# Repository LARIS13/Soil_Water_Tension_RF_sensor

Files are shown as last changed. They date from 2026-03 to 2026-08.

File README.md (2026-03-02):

# Soil_Water_Tension_RF_sensor
Implementation of Watermark sensor using arduino, attiny85 and RF modules including:

C++ code  
KiCad blueprints for PCB  
LaTeX document explaining theory, limitations and implementation of water measurement techniques.

# Dependencies:  
Manchester RF library: https://github.com/mchr3k/arduino-libs-manchester  
tinysnore is only used to sleep Attiny85 for more than the max Watchdog timer time, which is around 8 seconds: https://github.com/connornishijima/TinySnore

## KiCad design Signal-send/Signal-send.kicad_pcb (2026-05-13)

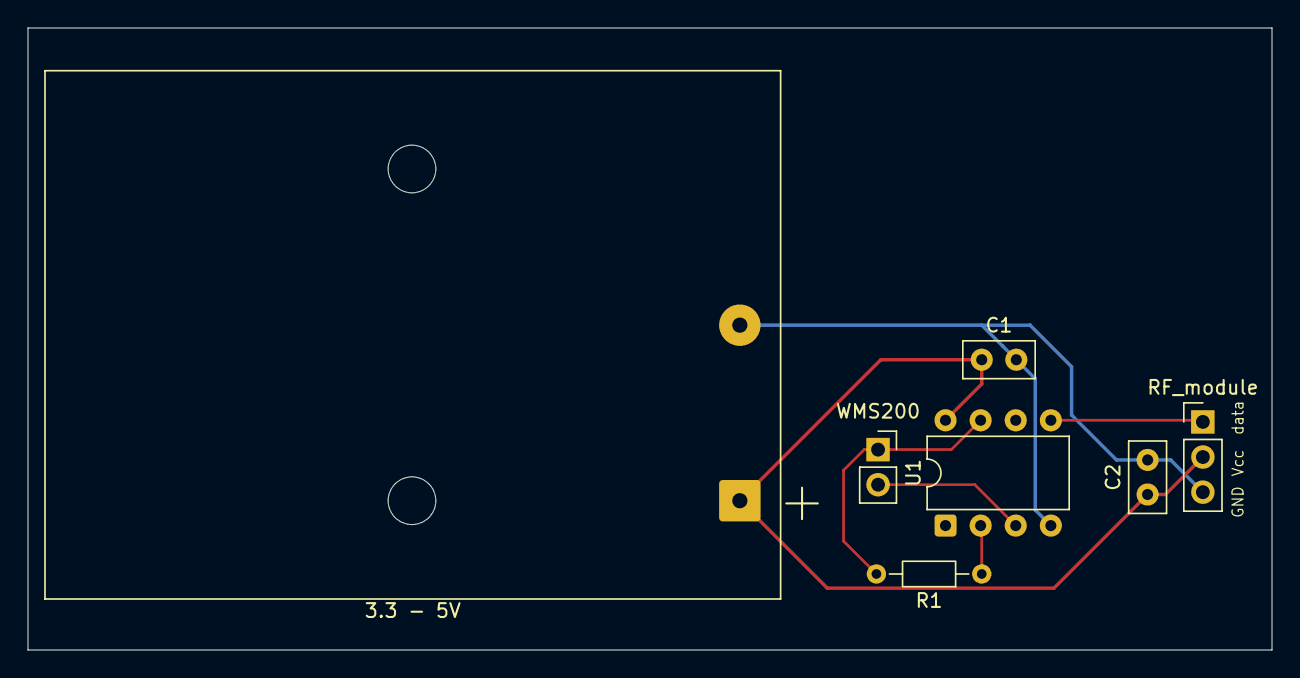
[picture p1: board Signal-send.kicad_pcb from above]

Board: 2 copper layers, 90.0 x 45.0 mm, 7 parts (0 on the bottom side), 5 nets.

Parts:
3.3 - 5V: BatteryHolder_Keystone_2479_3xAAA
C1: 0.1uF; C_Disc_D5.0mm_W2.5mm_P2.50mm
C2: 100uF; C_Disc_D5.0mm_W2.5mm_P2.50mm
R1: 10k; R_Axial_DIN0204_L3.6mm_D1.6mm_P7.62mm_Horizontal
RF_module: PinHeader_1x03_P2.54mm_Vertical
U1: ATtiny85V-10P; DIP-8_W7.62mm
WMS200: WMS200; PinSocket_1x02_P2.54mm_Vertical

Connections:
+5V: 3.3 - 5V.1, C1.1, C2.1, RF_module.2, U1.8 (VCC)
GNDREF: 3.3 - 5V.2, C1.2, C2.2, RF_module.3, U1.4 (GND)
unnamed: R1.2, U1.7 (PB2), WMS200.1
unnamed: R1.1, U1.2 (XTAL1/PB3)
unnamed: U1.3 (XTAL2/PB4), WMS200.2

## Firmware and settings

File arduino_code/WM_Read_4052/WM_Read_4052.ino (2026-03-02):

#include <math.h>

//************Documentation available at : www.irrometer.com/200ss.html ******************************************
// This program will read 3 Watermark(WM)Sensor(200-SS)and 1 Soil temperature sensor( 200TS) from Irrometer Co Inc.***
// Verson 1.0 updated 7/27/2023 by Jeremy Sullivan Irrometer Co Inc.**************************************************
//********************************************************************************************************************
// Watermark is a resistive sensor, so in order to check the accuracy of the resistive reading circuit a .....
// 10K resistor (1% precision) is used as a calibration reference only for prototype purposes.
// Code tested on Arduino Uno R3
// Purpose of this code is to demonstrate valid WM reading code, circuitry and excitation.
// This program uses a modified form of Dr. Shocks 1998 calibration equation
// Circuit will use a dual channel multiplexer to isolate sensors and will alternate polarity between the Sensor terminals for up to 4 resistive sensors( temperature/WM or calibration resistor)
// MUX control A and B to be controlled by PWM P4 & P3
// Sensor to be energized by PWM 5 or PWM 11, alternating between HIGH and LOW states
// MUX  enable/ disable PWM 6(LOW: Enable/High: Disable)
// Analog read channels to be used during MUX active : A1
// Channel 0 of MUX used for the temp sensor, channel 1 for Watermark 1, Channel 2 for Watermark 3 and and Channel 3 for Watermark 3
// In the absence of a Temp Sensor the program assigns 24 Degree C to temp for calibration of soil moisture tension

//NOTE: this code assumes a 10 bit ADC. Replace 1024 with 4096 if using a 12 bit ADC.
//NOTE: the 0.09 excitation time may not be sufficient depending on circuit design, cable lengths, voltage, etc. Increase if necessary to get accurate readings, do not exceed 0.2

//Truth table for MUX (B=PWM3 & A=PWM4)
//--B---A
//  0   0---- READ TEMPERATURE SENSOR
//  0   1---- READ WM1
//  1   0---- READ WM2
//  1   1---- READ WM3

// SET PWM5 or PWM11 HIGH/LOW ALTERNATELY TO EXCITE SENSOR

#define num_of_read 1 // number of iterations, each is actually two reads of the sensor (both directions)
const int Rx = 10000;  //fixed resistor attached in series to the sensor and ground...the same value repeated for all WM and Temp Sensor.
const long default_TempC = 24;
const long open_resistance = 35000; //check the open resistance value by replacing sensor with an open and replace the value here...this value might vary slightly with circuit components
const long short_resistance = 200; // similarly check short resistance by shorting the sensor terminals and replace the value here.
const long short_CB = 240, open_CB = 255 ;
const int SupplyV = 5; // Assuming 5V output for SupplyV, this can be measured and replaced with an exact value if required
const float cFactor = 1.1; //correction factor optional for adjusting curves. Traditionally IRROMETER devices used a different reading method, voltage divider circuits often require this adjustment to match exactly.
int i, j = 0, WM1_CB = 0, WM2_CB = 0, WM3_CB = 0;
float SenV10K = 0, SenVTempC = 0, SenVWM1 = 0, SenVWM2 = 0, ARead_A1 = 0, ARead_A2 = 0, WM3_Resistance = 0, WM2_Resistance = 0, WM1_Resistance = 0, TempC_Resistance = 0, TempC = 0;

void setup()
{
  // initialize serial communications at 9600 bps:
  Serial.begin(9600);

  // initialize the digital pins as outputs
  pinMode(3, OUTPUT);  //used for S0 control of the MUX 0-1
  pinMode(4, OUTPUT);  //used for S1 control of the MUX 0-1
  pinMode(5, OUTPUT);  //Sensor Vs or GND
  pinMode(6, OUTPUT);  //Enable disable MUX 0-1
  pinMode(11, OUTPUT);  //Sensor Vs or GND

  delay(100);   // time in milliseconds, wait 0.1 minute to make sure the OUTPUT is assigned
}

void loop()
{
  while (j == 0)
  {

    //enable the MUX
    digitalWrite(6, LOW);
    
    //Read the temp sensor
    delay(100); //0.1 second wait before moving to next channel or switching MUX
    //address the MUX (channel 1)
    
    digitalWrite(3, LOW);
    digitalWrite(4, LOW);

    delay(10); //wait for MUX
    
    TempC_Resistance = readWMsensor();

    //Read the first Watermark sensor
    delay(100); //0.1 second wait before moving to next channel or switching MUX
    //address the MUX
    digitalWrite(3, LOW);
    digitalWrite(4, HIGH);

    delay(10); //wait for the MUX

    WM1_Resistance = readWMsensor();

    //Read the second Watermark sensor
    delay(100); //0.1 second wait before moving to next channel or switching MUX
    //address the MUX 
    digitalWrite(3, HIGH);
    digitalWrite(4, LOW);

    delay(10); //wait for MUX

    WM2_Resistance = readWMsensor();

    //Read the third Watermark sensor
    delay(100); //0.1 second wait before moving to next channel or switching MUX
    //address the MUX
    digitalWrite(3, HIGH);
    digitalWrite(4, HIGH);

    delay(10); //wait for the MUX

    WM3_Resistance = readWMsensor();

    delay(100); //0.1 second wait before moving to next channel or switching MUX


    digitalWrite(6, HIGH);   //Disable MUX 0-1 pair
    delay(100); //0.1 second wait before moving to next channel or switching MUX

    //convert the measured reistance to kPa/centibars of soil water tension
    TempC = myTempvalue(TempC_Resistance);
    WM1_CB = myCBvalue(WM1_Resistance, TempC, cFactor);
    WM2_CB = myCBvalue(WM2_Resistance, TempC, cFactor);
    WM3_CB = myCBvalue(WM3_Resistance, TempC, cFactor);

    //*****************output************************************
    Serial.print("Temperature(C)= ");
    Serial.println(abs(TempC));
    Serial.print("\n");
    Serial.print("WM1 Resistance(Ohms)= ");
    Serial.println(WM1_Resistance);
    Serial.print("WM2 Resistance(Ohms)= ");
    Serial.println(WM2_Resistance);
    Serial.print("WM3 Resistance(Ohms)= ");
    Serial.println(WM3_Resistance);
    Serial.print("WM1(cb/kPa)= ");
    Serial.println(abs(WM1_CB));
    Serial.print("WM2(cb/kPa)= ");
    Serial.println(abs(WM2_CB));
    Serial.print("WM3(cb/kPa)= ");
    Serial.println(abs(WM3_CB));
    Serial.print("\n");

    delay(200000);
    //j=1;
  }
}


int myCBvalue(int res, float TC, float cF) {   //conversion of ohms to CB
  int WM_CB;
  float resK = res / 1000.0;
  float tempD = 1.00 + 0.018 * (TC - 24.00);

  if (res > 550.00) { //if in the normal calibration range
    if (res > 8000.00) { //above 8k
      WM_CB = (-2.246 - 5.239 * resK * (1 + .018 * (TC - 24.00)) - .06756 * resK * resK * (tempD * tempD)) * cF;
    } else if (res > 1000.00) { //between 1k and 8k
      WM_CB = (-3.213 * resK - 4.093) / (1 - 0.009733 * resK - 0.01205 * (TC)) * cF ;
    } else { //below 1k
      WM_CB = -(resK * 23.156 - 12.736) * tempD;
    }
  } else { //below normal range but above short (new, unconditioned sensors)
    if (res > 300.00)  {
      WM_CB = 0.00;
    }
    if (res < 300.00 && res >= short_resistance) { //wire short
      WM_CB = short_CB; //240 is a fault code for sensor terminal short
      Serial.print("Sensor Short WM \n");
    }
  }
  if (res >= open_resistance || res==0) {

    WM_CB = open_CB; //255 is a fault code for open circuit or sensor not present

  }
  return WM_CB;
}

float myTempvalue(float temp) {

    float TempC = (-23.89 * (log(TempC_Resistance))) + 246.00;
    if (TempC_Resistance < 0 || TempC_Resistance > 30000 )
    {
      Serial.print("Temperature Sensor absent, using default \n");
      TempC = 24.0;
    }
    return TempC;
 
}


float readWMsensor() {  //read ADC and get resistance of sensor

  ARead_A1 = 0;
  ARead_A2 = 0;

  for (i = 0; i < num_of_read; i++) //the num_of_read initialized above, controls the number of read successive read loops that is averaged.
  {

    digitalWrite(5, HIGH);   //Set pin 5 as Vs
    delayMicroseconds(90); //wait 90 micro seconds and take sensor read
    ARead_A1 += analogRead(A1); // read the analog pin and add it to the running total for this direction
    digitalWrite(5, LOW);      //set the excitation voltage to OFF/LOW

    delay(100); //0.1 second wait before moving to next channel or switching MUX

    // Now lets swap polarity, pin 5 is already low

    digitalWrite(11, HIGH); //Set pin 11 as Vs
    delayMicroseconds(90); //wait 90 micro seconds and take sensor read
    ARead_A2 += analogRead(A1); // read the analog pin and add it to the running total for this direction
    digitalWrite(11, LOW);      //set the excitation voltage to OFF/LOW
  }

  SenVWM1 = ((ARead_A1 / 1024) * SupplyV) / (num_of_read); //get the average of the readings in the first direction and convert to volts
  SenVWM2 = ((ARead_A2 / 1024) * SupplyV) / (num_of_read); //get the average of the readings in the second direction and convert to volts

  double WM_ResistanceA = (Rx * (SupplyV - SenVWM1) / SenVWM1); //do the voltage divider math, using the Rx variable representing the known resistor
  double WM_ResistanceB = Rx * SenVWM2 / (SupplyV - SenVWM2);  // reverse
  double WM_Resistance = ((WM_ResistanceA + WM_ResistanceB) / 2); //average the two directions
  return WM_Resistance;
}

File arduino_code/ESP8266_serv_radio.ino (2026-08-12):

#include <ESP8266WiFi.h>
#include <WiFiClient.h>
#include <ESP8266WebServer.h>
#include <ESP8266mDNS.h>
#include <WiFiUdp.h>
#include <Manchester.h>
#include <time.h>

const int Rx = 10000;  //fixed resistor attached in series to the sensor and ground...the same value repeated for all WM and Temp Sensor.
const long default_TempC = 20;
const long open_resistance = 35000; //check the open resistance value by replacing sensor with an open and replace the value here...this value might vary slightly with circuit components
const long short_resistance = 200; // similarly check short resistance by shorting the sensor terminals and replace the value here.
const long short_CB = 240, open_CB = 255 ;
const int SupplyV = 5; // Assuming 5V output for SupplyV, this can be measured and replaced with an exact value if required
const float cFactor = 1.1; //correction factor optional for adjusting curve, 1.1 recommended to match IRROMETER devices as well as CS CR1000

#define MY_TZ "CST6"
#ifndef STASSID
#define STASSID "Totalplay-76A6"
#define STAPSK "76A62E0DZBSSSGqk"
#endif

#define RX_PIN 4 //any pin can transmit
#define LED_PIN 2
#define BUFFER_SIZE 4
#define num_sens 4

uint8_t size;
uint8_t buffer[BUFFER_SIZE] = {};

const char* ssid = STASSID;
const char* password = STAPSK;

unsigned int localPort = 123;

IPAddress timeServerIP;  // time.nist.gov NTP server address
const char* NTPServerName = "mx.pool.ntp.org";

const int NTP_PACKET_SIZE = 48;  // NTP time stamp is in the first 48 bytes of the message

byte NTPBuffer[NTP_PACKET_SIZE] = {};  // buffer to hold incoming and outgoing packets

// A UDP instance to let us send and receive packets over UDP
WiFiUDP UDP;

//Secure client for google sheets connection
WiFiClientSecure secureClient;
//----------------------------------------Host & httpsPort
const char* host = "script.google.com";
const int httpsPort = 443;
//ID for google sheet
String GAS_ID = "AKfycbyZUmnkbehKTs4XBfrhy3ALrgaAvBeiw3Qt3fuprX7xDVVYYRtO6HuookU0MZy900m_mw";

ESP8266WebServer server(80);

unsigned long intervalNTP = 60000; // Request NTP time every minute
unsigned long prevNTP = 0;
unsigned long lastNTPResponse = millis();
unsigned long currentMillis = millis();
uint32_t timeUNIX = 0;
uint32_t actualTime = timeUNIX + (currentMillis - lastNTPResponse)/1000;
unsigned long prevActualTime = 0;
time_t miTiempo = static_cast<time_t>(actualTime);
struct tm *timeinfo = localtime(&miTiempo);

tm* readtimes[num_sens];

//conversion of ohms to CB
int myCBvalue(int ARead_A1, int ARead_A2, float TC, float cF) {   //conversion of ohms to CB
  float SenVWM1 = ((ARead_A1 / 255.0f) * SupplyV); //get the average of the readings in the first direction and convert to volts
  float SenVWM2 = ((ARead_A2 / 255.0f) * SupplyV); //get the average of the readings in the second direction and convert to volts
  double WM_ResistanceA = (Rx * (SupplyV - SenVWM1) / SenVWM1); //do the voltage divider math, using the Rx variable representing the known resistor
  double WM_ResistanceB = Rx * SenVWM2 / (SupplyV - SenVWM2);  // reverse
  double res = ((WM_ResistanceA + WM_ResistanceB) / 2.0); //average the two directions
  Serial.println("Calculating ");
  Serial.println(res);
  int WM_CB;
  float resK = res / 1000.0;
  float tempD = 1.00 + 0.018 * (TC - 24.00);

  if (res > 550.00) { //if in the normal calibration range
    if (res > 8000.00) { //above 8k
      WM_CB = (-2.246 - 5.239 * resK * (1 + .018 * (TC - 24.00)) - .06756 * resK * resK * (tempD * tempD)) * cF;
    } else if (res > 1000.00) { //between 1k and 8k
      WM_CB = (-3.213 * resK - 4.093) / (1 - 0.009733 * resK - 0.01205 * (TC)) * cF ;
    } else { //below 1k
      WM_CB = -(resK * 23.156 - 12.736) * tempD;
    }
  } else { //below normal range but above short (new, unconditioned sensors)
    if (res > 300.00)  {
      WM_CB = 0.00;
    }
    if (res < 300.00 && res >= short_resistance) { //wire short
      WM_CB = short_CB; //240 is a fault code for sensor terminal short
      Serial.print("Sensor Short WM \n");
    }
  }
  if (res >= open_resistance || res==0) {

    WM_CB = open_CB; //255 is a fault code for open circuit or sensor not present

  }
  return WM_CB;
}

const char HTML_PAGE[] PROGMEM = R"rawliteral(
<!DOCTYPE html>
<html lang="en">
<head>
<meta charset="UTF-8">
<meta name="viewport" content="width=device-width,initial-scale=1">
<title>ESP8266 Sensor Hub</title>
<style>
  :root {
    --bg:     #0d1117;
    --card:   #161b22;
    --border: #30363d;
    --accent: #58a6ff;
    --green:  #3fb950;
    --text:   #e6edf3;
    --muted:  #8b949e;
    --font:   'Courier New', monospace;
  }
  * { box-sizing: border-box; margin: 0; padding: 0; }
  body {
    background: var(--bg);
    color: var(--text);
    font-family: var(--font);
    min-height: 100vh;
    display: flex;
    flex-direction: column;
    align-items: center;
    justify-content: center;
    padding: 24px;
  }
  header {
    text-align: center;
    margin-bottom: 32px;
  }
  header h1 {
    font-size: 1.1rem;
    letter-spacing: 0.2em;
    text-transform: uppercase;
    color: var(--accent);
  }
  header p {
    font-size: 0.7rem;
    color: var(--muted);
    margin-top: 6px;
    letter-spacing: 0.1em;
  }
  .grid {
    display: grid;
    grid-template-columns: 1fr 1fr;
    gap: 16px;
    width: 100%;
    max-width: 480px;
  }
  @media (max-width: 360px) {
    .grid { grid-template-columns: 1fr; }
  }
  .card {
    background: var(--card);
    border: 1px solid var(--border);
    border-radius: 8px;
    padding: 20px 16px;
    position: relative;
    overflow: hidden;
  }
  .card::before {
    content: '';
    position: absolute;
    top: 0; left: 0; right: 0;
    height: 2px;
    background: var(--green);
  }
  .card .label {
    font-size: 0.65rem;
    letter-spacing: 0.15em;
    color: var(--muted);
    margin-bottom: 12px;
  }
  .card .value {
    font-size: 2.4rem;
    font-weight: bold;
    color: var(--text);
    line-height: 1;
  }
  .card .unit {
    font-size: 1rem;
    color: var(--accent);
    margin-left: 4px;
  }
  .card .ts {
    font-size: 0.58rem;
    color: var(--muted);
    margin-top: 12px;
  }
  .card .ts span {
    color: var(--green);
  }
  footer {
    margin-top: 28px;
    font-size: 0.6rem;
    color: var(--muted);
    letter-spacing: 0.1em;
    text-align: center;
  }
</style>
</head>
<body>
<header>
  <h1>&#9632; Huerto La Pausa </h1>
  <p>ESP8266 &bull; %IP%</p>
</header>

<div class="grid">

  <div class="card">
    <div class="label">Sensor: %S1_LABEL%</div>
    <div class="value">%S1_VALUE%<span class="unit">%S1_UNIT%</span></div>
    <div class="ts">Updated:<br><span>%S1_TS%</span></div>
  </div>

  <div class="card">
    <div class="label">%S2_LABEL%</div>
    <div class="value">%S2_VALUE%<span class="unit">%S2_UNIT%</span></div>
    <div class="ts">Updated:<br><span>%S2_TS%</span></div>
  </div>

</div>
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

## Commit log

2026-02-01 Added KiCad files of sending circuit
    [Signal-send.kicad_pcb, Signal-send.kicad_sch]
2026-03-02 Added code for Reciever and Transmitter, aswell as examples for math regarding sensor reading
2026-05-13 Added files of SWT_TX_V1
    also added gerbers of V1
    [Signal-send.kicad_pcb]
2026-07-16 Add ESP8266 server code for sensor data handling
    Added esp8266 support and example using it as server for handling sensor data, getting a time for the reading, hosting a webpage with the latest readings and logging historical data to google sheets 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
